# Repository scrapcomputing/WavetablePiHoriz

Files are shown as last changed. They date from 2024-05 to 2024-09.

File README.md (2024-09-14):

# Horizontal WavetablePi

This is the horizontal version of [WavetablePi](https://github.com/scrapcomputing/WavetablePi).
It is a wavetable module based on the Raspberry Pi Zero 2 W running [mt32-pi](https://github.com/dwhinham/mt32-pi).
It is capable of emulating several midi synthesizers, including mt32, sc55 and general midi with custom sound fonts.
For a complete feature list please refer to the [mt32-pi](https://github.com/dwhinham/mt32-pi) project.

### Assembling the Horizontal WavetablePi (by sweetlilmre)
An assembly guide can be found [here](assembly.md).

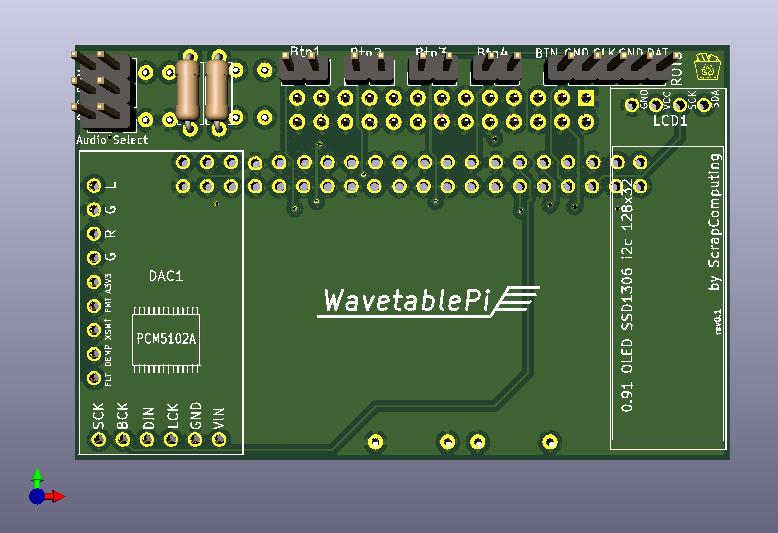
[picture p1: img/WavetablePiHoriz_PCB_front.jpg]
WavetablePi PCB Front

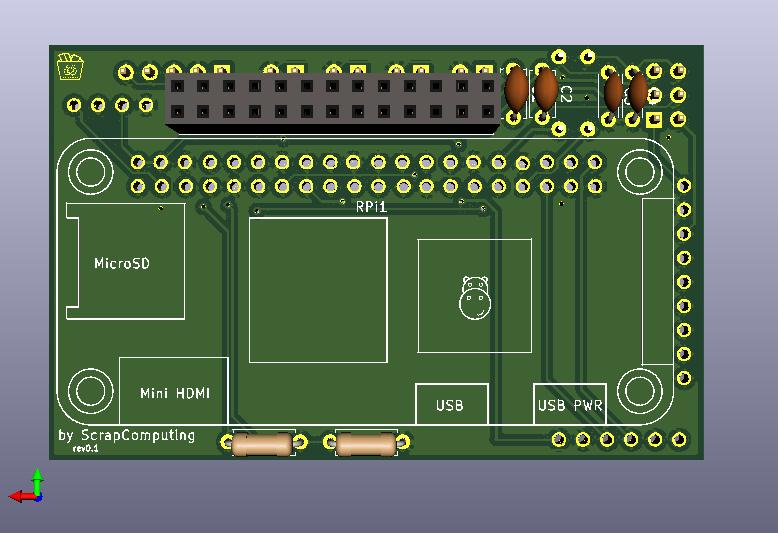
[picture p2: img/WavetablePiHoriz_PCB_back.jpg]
WavetablePi PCB Back

WavetablePi Schematic
</p>

- 5.25 drive bay faceplates (by Michael Swimm) https://www.thingiverse.com/thing:6652143

# New Features
- This version also includes headers for the mt32-pi buttons and rotary encoder.

# Bill of materials

The gerber can be found in the [releases](https://github.com/scrapcomputing/WavetablePiHoriz/releases)

Item                                     | #   | Description
-----------------------------------------|-----|-----------------------------------------
Raspberry Pi Zero 2 W                    | 1   | The older RPi Zero is not fast enough
40-pin 2x20 male header 2.54mm pitch     | 1   | For attaching the RPi to the board.
26-pin 2x13 female header 2.54mm pitch   | 1   | For attaching the board to the wavetable header
6-pin 2x3 pin male header 2.54mm pitch   | 1   | For the audio select jumpers
2-pin 1x2 pin male header 2.54mm pitch   | 4   | (Optional) Headers for mt32-pi buttons
5-pin 1x5 pin male header 2.54mm pitch   | 1   | (Optional) Header for mt32-pi rotary encoder
Jumper 2.54mm pitch                      | 2   | Jumpers for the audio selection header
Capacitor 10uF through-hole ceramic      | 2   |
Capacitor 100nF through-hole ceramic     | 2   | C3 and C4 which form the PWM audio low-pass filter along with R3 and R4. 100nF is for a 1.6KHz cutoff frequency. Use lower values for higher cutoff
Resistor 22K Ohm                         | 1   |
Resistor 10K Ohm                         | 1   |
Resistor 1K Ohm                          | 2   | R3 and R4, which along with C3 and C4 form a low-pass filter of the PWM audio
0.91 OLED SSD1306 I2C 128x32 module      | 1   | (Optional)
PCM5102A I2S DAC Module (aka GY PCM5120) | 1   | (Optional but highly recommended) Please check the PCB for the supported dimensions and form factor!

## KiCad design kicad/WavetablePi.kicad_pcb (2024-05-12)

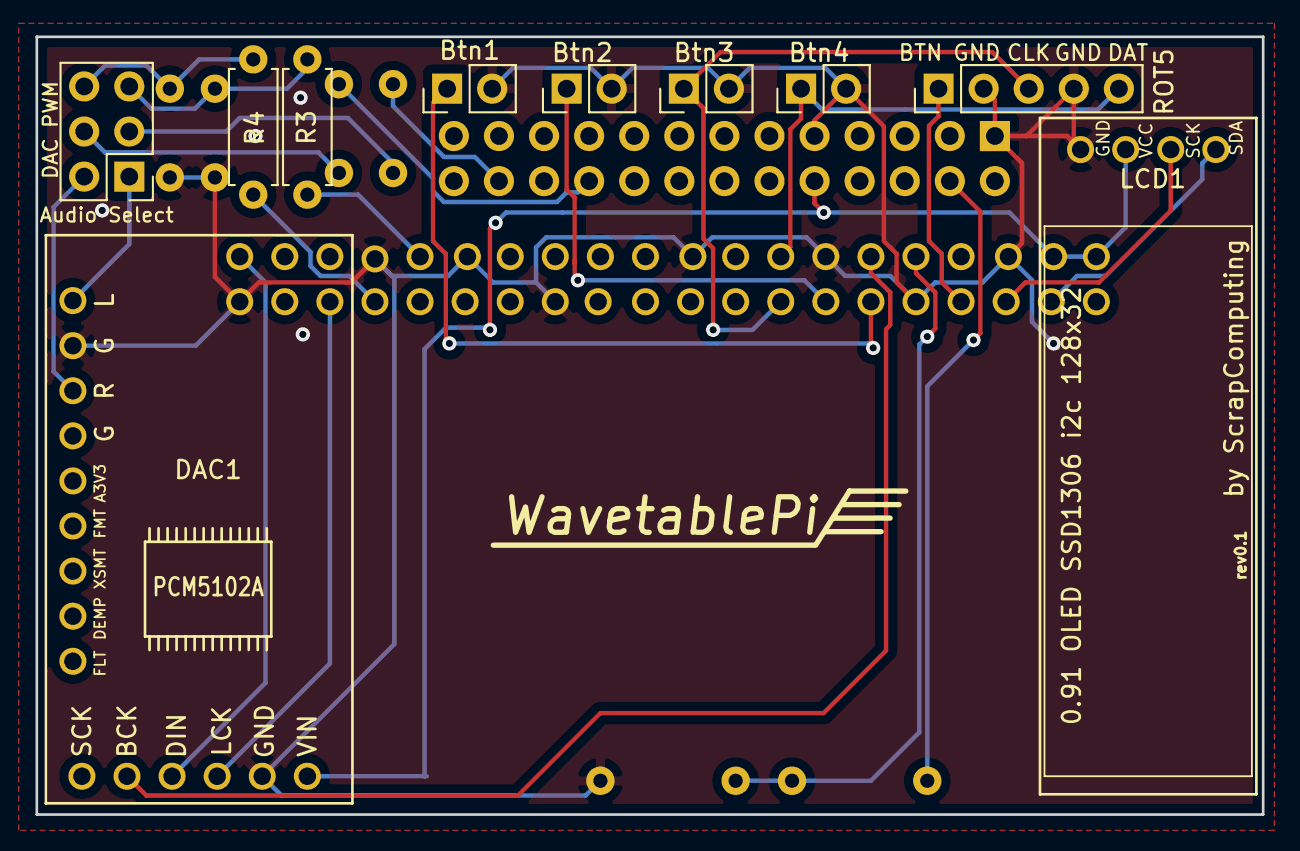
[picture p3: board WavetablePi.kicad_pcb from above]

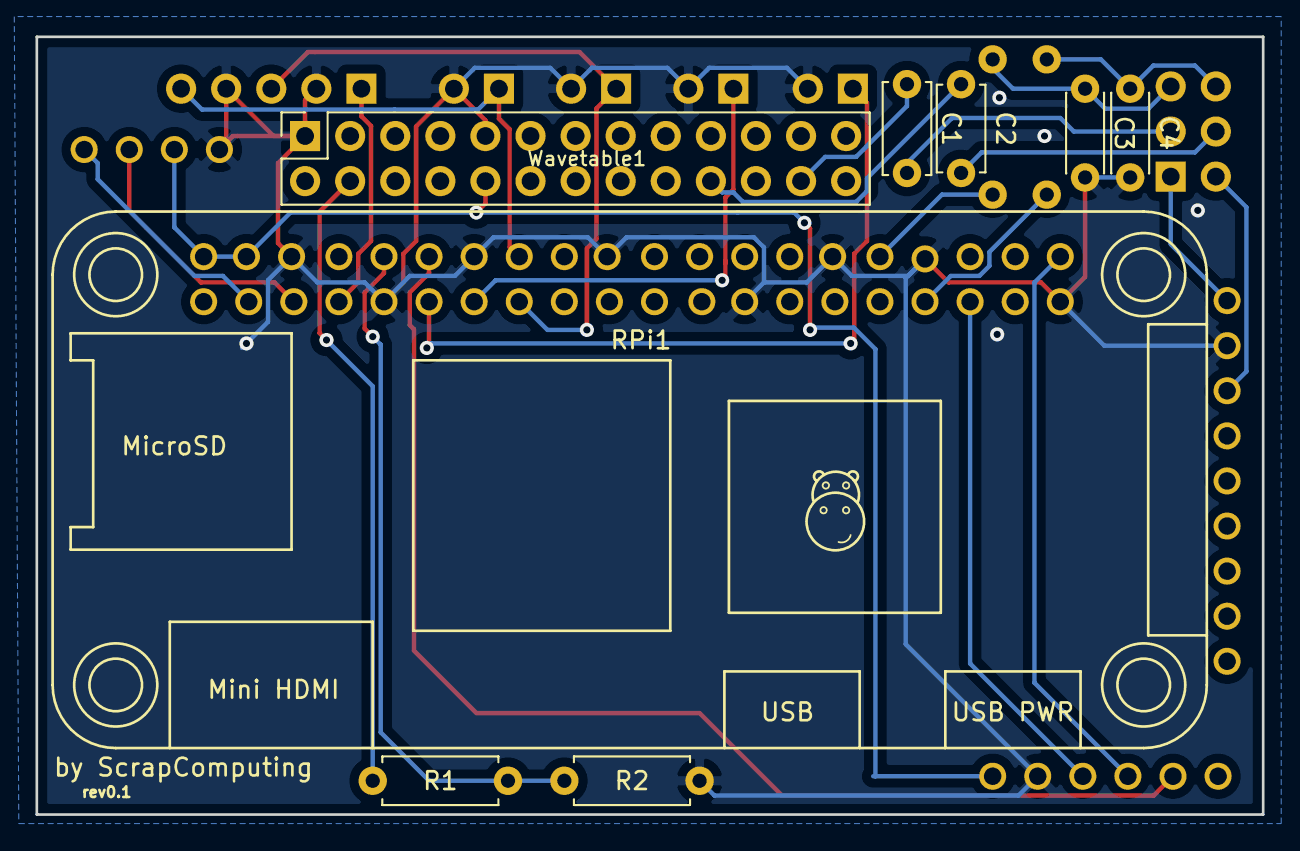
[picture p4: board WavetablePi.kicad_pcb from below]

Board: 2 copper layers, 69.1 x 43.8 mm, 18 parts (8 on the bottom side), 24 nets.

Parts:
Audio_Select1: Conn_02x03_Odd_Even; PinHeader_2x03_P2.54mm_Vertical
Btn1: Btn1; PinHeader_1x02_P2.54mm_Vertical
Btn2: Btn2; PinHeader_1x02_P2.54mm_Vertical
Btn3: Btn3; PinHeader_1x02_P2.54mm_Vertical
Btn4: Btn4; PinHeader_1x02_P2.54mm_Vertical
C1: 10uF; C_Disc_D5.0mm_W2.5mm_P5.00mm
C2: 10uF; C_Disc_D4.7mm_W2.5mm_P5.00mm
C3, C4: 100nF; C_Disc_D4.3mm_W1.9mm_P5.00mm
DAC1: GY_PCM5102A
LCD1: LCD_0.91_OLED
R1: 10K; R_Axial_DIN0207_L6.3mm_D2.5mm_P7.62mm_Horizontal
R2: 22K; R_Axial_DIN0207_L6.3mm_D2.5mm_P7.62mm_Horizontal
R3, R4: 1K; R_Axial_DIN0207_L6.3mm_D2.5mm_P7.62mm_Horizontal
ROT5: ROTARY; PinHeader_1x05_P2.54mm_Vertical
RPi1: RPiZero2W
Wavetable1: Conn_02x13_Odd_Even; PinSocket_2x13_P2.54mm_Vertical

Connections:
+5V: DAC1.6, LCD1.3, RPi1.2, RPi1.4, Wavetable1.10
GND: Btn1.2, Btn2.2, Btn3.2, Btn4.2, C3.2, C4.2, DAC1.5, DAC1.14, LCD1.4, R2.2, ROT5.2, ROT5.4, RPi1.6, RPi1.9, RPi1.14, RPi1.20, RPi1.25, RPi1.30, RPi1.34, RPi1.39, Wavetable1.1, Wavetable1.9
GP4: ROT5.1, RPi1.7
GP17: Btn1.1, RPi1.11
GP22: Btn3.1, ROT5.3, RPi1.15
GP23: Btn4.1, ROT5.5, RPi1.16
GP27: Btn2.1, RPi1.13
unnamed: Audio_Select1.1, DAC1.15
unnamed: Audio_Select1.2, DAC1.13
unnamed: Audio_Select1.3, C1.2
unnamed: Audio_Select1.4, C2.2
unnamed: Audio_Select1.5, C3.1, R3.1
unnamed: Audio_Select1.6, C4.1, R4.1
unnamed: C1.1, Wavetable1.24
unnamed: C2.1, Wavetable1.20
unnamed: DAC1.2, RPi1.12
unnamed: DAC1.3, RPi1.40
unnamed: DAC1.4, RPi1.35
unnamed: LCD1.1, RPi1.3
unnamed: LCD1.2, RPi1.5
unnamed: R1.1, R2.1, RPi1.10
unnamed: R1.2, Wavetable1.4
unnamed: R3.2, RPi1.32
unnamed: R4.2, RPi1.33

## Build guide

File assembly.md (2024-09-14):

# Assembling the Horizontal WavetablePi

An idiot's guide to assembling the Horizontal WavetablePi by @sweetlilmre

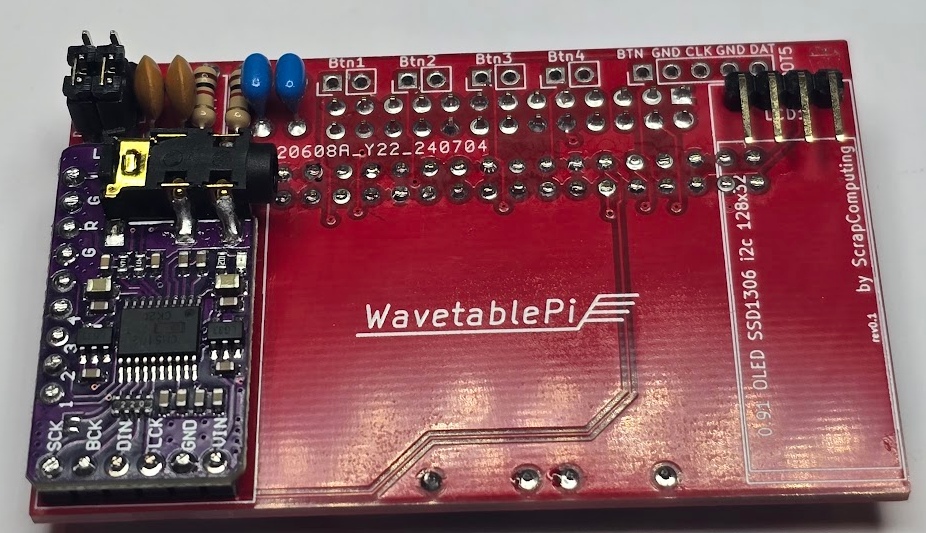
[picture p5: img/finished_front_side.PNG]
WavetablePi completed, front side


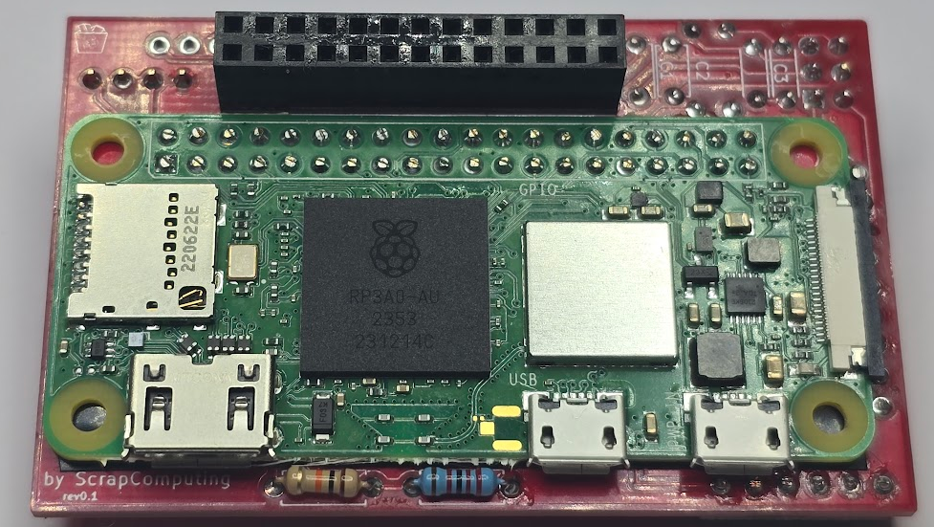
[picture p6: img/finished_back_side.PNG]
WavetablePi completed, front side


## Introduction

I found assembling this board quite tricky, especially in terms of the order of operations and made several errors on my first attempt. I hope this guide will help you avoid the same mistakes I made.

## Front side assembly

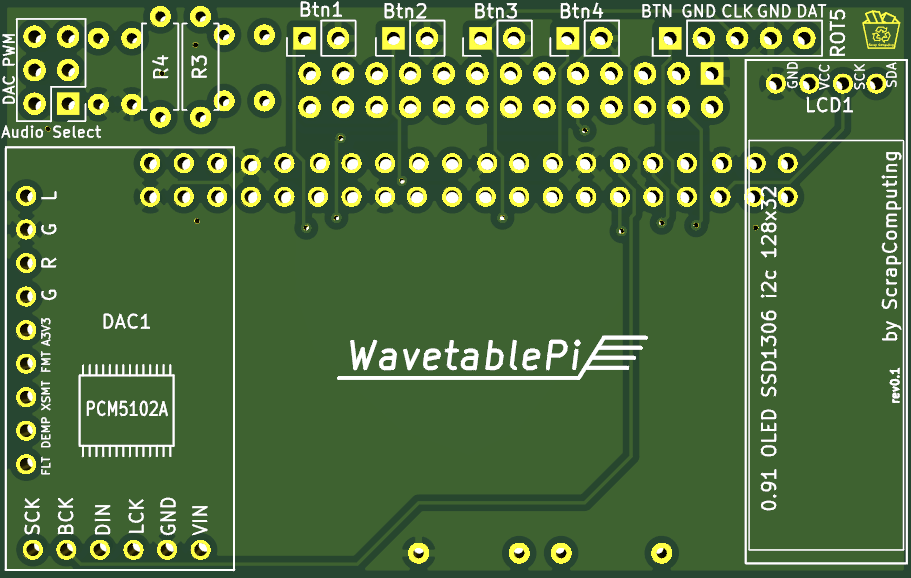
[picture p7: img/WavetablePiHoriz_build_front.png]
WavetablePi PCB Front


### Front side assembly steps:

- Solder resistors R3 and R4 (1K Ohm) as shown
- Capacitors C1 - C4 have silk screen markings on the back of the board. Solder them on the front side of the board instead to provide extra clearance around the Wavetable header. On this side:
  - Capacitors C3 and C4 100nF: left of R4, R3
  - Capacitors C1 and C2 10uF: right of R4, R3
- If you are using the optional DAC module:
    - Place the pins into the holes.
    - Place the DAC onto the pins to align the pins properly.
    - Solder the header pins to the back side of the board.
    - Do *not* solder the DAC module yet.
  - Clip the pins flush on the back side of the board.
- Solder the Audio Select header.
- Solder the optional headers as required.
  - **NOTE**: I would suggest using right angled pin headers to reduce overall component height on this side e.g. LCD header pins facing down, Btn1 - Btn4 and ROT5 pin facing up.

## Back side assembly

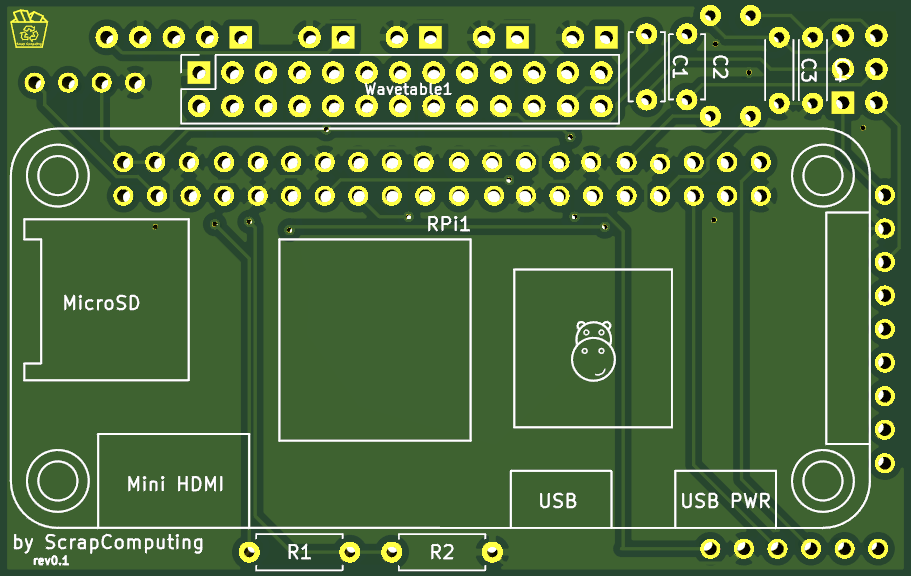
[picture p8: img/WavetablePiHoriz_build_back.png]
WavetablePi PCB Back


### Back side assembly steps:

- Solder resistors R1 (10K Ohm) and R2 (22K Ohm) as shown.
- Soldering the Pi:
  - We will solder the Pi flush to the board:
    - Mask off the area that will be between the Pi and the board with tape to prevent any potential shorts / issues. Kapton tape or even elecrical tape will do.
  - Soldering the 40-pin header and removing the plastic spacer can be tricky:
    - Push the plastic spacer of the 40 pin header down the pins, using a hard flat surface to make sure all pins are aligned:

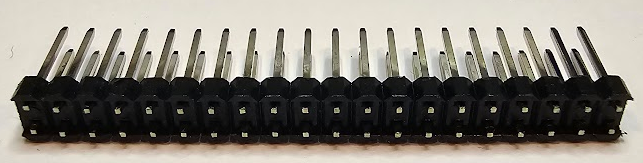
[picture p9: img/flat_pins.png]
    - 

    - Push the header through the holes on the front of the board:

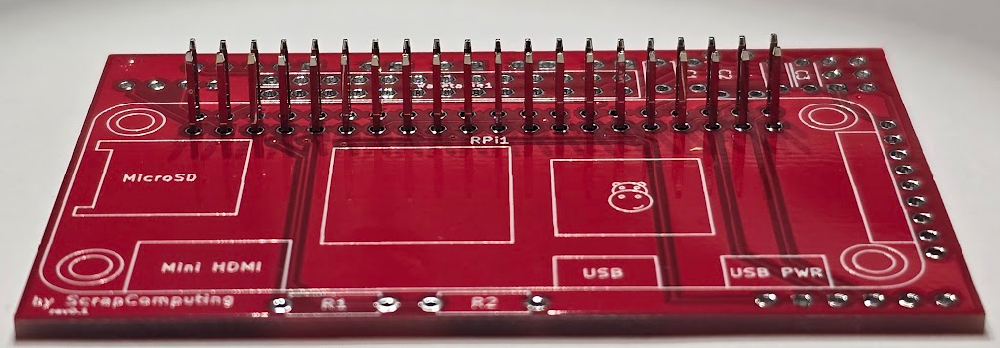
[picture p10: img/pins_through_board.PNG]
    - 

    - Place the Pi on top of the header pins, push the Pi down against the board and solder the pins to the Pi.
    - Trim the pins on the Pi side of the board and flip the board over.
    - Working from one end, pry up the plastic spacer and remove it (it may help to use a cutting tool to separate the spacer every 3 or 4 sets of pins).
    - Solder the pins to the board on the front side.
    - Trim the pins.
- Flip the board back over, place and then solder the Wavetable header.

## Final assembly

- If you are using the DAC module:
  - ensure that the jumpers on the DAC are configured according to [this guide](https://github.com/dwhinham/mt32-pi/wiki/GY-PCM5102-DAC-module) before soldering the DAC to the board.

  - PCM5102A jumpers

  - Solder the DAC module to the board.

- Set the jumpers on the Audio Select header to the desired configuration.

- Enjoy your new Horizontal WavetablePi!

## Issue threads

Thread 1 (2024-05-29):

Tested and is working.

Therrixxe, 2024-05-29:
When building it I moved R1 and R2 to the other side just to prevent issues with mounting the raspberry pi zero 2. Spacing is a little tight when mounting the resistors. I have tested the LCD and buttons however I haven't tested the rotary encoder yet. Thank you for making the horizontal version so quickly.

I have tested it on an ESS ISA card and PicoGUS in MPU-401mode and it works perfectly.

scrapcomputing, 2024-06-06:
Great! Thanks for the feedback. I will try to fix the spacing for R1 and R2 in a future revision.

Therrixxe, 2024-06-09:
I have worked up two faceplates for the wavetable header. https://www.thingiverse.com/thing:6652143

One using round buttons and one using 3d printed square buttons. Still need to laser cut the acrylic for the square one. I was going to use the label SC-32_PIWT_ with your logo.

scrapcomputing, 2024-06-11:
Awesome! Thanks for sharing your project, I will add a link to it in the project's README.

Closed 2024-06-11.

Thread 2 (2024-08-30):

C1 - C4 placement issue with Diamond Monster Sound MX300

sweetlilmre, 2024-08-30:
The position of the C1-C4 capacitors interferes with the CD/AUX/MODEM connectors on this card.
Suggest moving the component to the opposite side of the board, this should be fairly simple, all that would be needed is an update to the silkscreen. See e.g.: 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

scrapcomputing, 2024-09-03:
Thanks for the feedback. Yeah I might add the silk screen on both sides in a follow up revision. Or perhaps a version with SMD parts would be more suitable.

sweetlilmre, 2024-09-04:
Just to close this off, swapping the orientation worked well!
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

Closed 2024-09-04.

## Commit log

2024-05-12 Rev 0.1
    [WavetablePi.kicad_pcb, WavetablePi.sch]
2024-09-12 Added assembly guide
